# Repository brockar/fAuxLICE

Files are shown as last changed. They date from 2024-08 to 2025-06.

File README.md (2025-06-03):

# fAuxLICE

A 3D printable Alice-like mechanical keyboard.

outside

## Layout

layout

[Keyboard Layout Editor](http://www.keyboard-layout-editor.com/#/gists/7f17a55de07d88c1f975089b07f053b1)

## Components

### Required components

- 1x Arduino Pro Micro
- 64× switches of your choice
- 108-key keycap set
- 64× diodes
- Wires
- 14× M3×16 countersunk screws
- 2× M3×12 countersunk screws

### Optional components

- 4× plate-mounted Costar stabilizers or
- 4x plate-mounted Cherry Mx Spec (Durock Piano)
- 1× M3×8 countersunk screw
- 1× M3×10 countersunk screw
- 1× M3×12 countersunk screw
- 1× M3×16 countersunk screw
- 1× M3×20 countersunk screw

The optional components are for reinforcing the top halves. They're not required.  
A proper glue-up would probably be enough for the two halves.

## Wiring diagram

The keyboard is wired in a 10-row, 7-column configuration.  
We have to solder a cable between the left and right columns as shown in the picture.
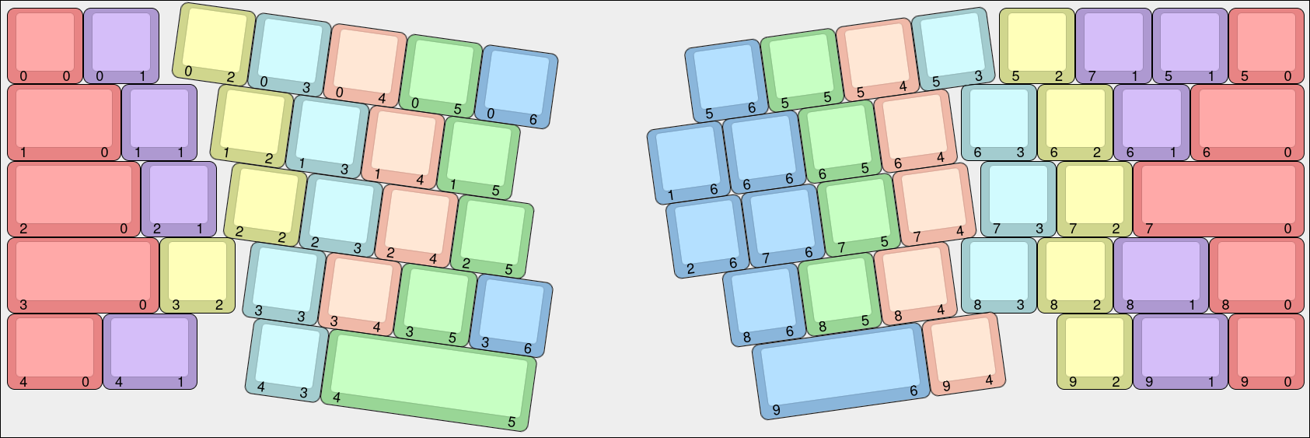
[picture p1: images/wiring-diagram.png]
wiring


The way to connect the rows/columns to the Pro Micro is defined in `keyboard.json`:

```json
"rows": ["B5", "B4", "E6", "D7", "C6", "F4", "D4", "D0", "D1", "D2"],
"cols": ["B6", "B2", "B3", "B1", "F7", "F6", "F5"]
```

## Build notes

The accent pieces have an extra 5mm sticking out. You should be able to cut them to the perfect length, and make the transitions between the two seamless. Glue the accent pieces to the bottom halves.

The halves do not lock into each other. I used a combination of glue and diode trimmings melted into the plastic.

## Firmware

[firmware explain](firmware/readme.md)

The firmware included is for the Arduino Pro Micro board.  
You can just flash `fauxlice_vial.hex` with [QMK-Toolbox](https://qmk.fm/toolbox) or [QMK-CLI](https://docs.qmk.fm/cli).

If you want to change something, download the vial code, create a folder in `vial-qmk/keyboards/` called `fauxlice`, copy what is in `firmware` into that folder, and modify what you need.  
Finally, while in `vial-qmk` run `make fauxlice:vial` and flash the .hex file.

## Build

1. Add mid top screws.
2. Add switches south pole, with the hole to the bottom.
3. Solder the diodes on the left pin (the diagram is top view, but when you're soldering, you're viewing from the bottom).
4. Solder cable as shown on the wiring diagram, and connect the columns to the other side as shown.
5. Now solder the PM as shown in the `keyboard.json`.

Note: If you'll use plate-mounted stabilizers, you should add them before soldering the switches.

## Special thanks to

- [mnt](https://www.instagram.com/mnt.designs/)
- [zykrah](https://zykrah.me/)

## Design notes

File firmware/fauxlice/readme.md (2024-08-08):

# fauxlice

fauxlice

*A short description of the keyboard/project*

* Keyboard Maintainer: [brockar](https://github.com/brockar)
* Hardware Supported: *The PCBs, controllers supported*
* Hardware Availability: *Links to where you can find this hardware*

Make example for this keyboard (after setting up your build environment):

    make fauxlice:default

Flashing example for this keyboard:

    make fauxlice:default:flash

See the [build environment setup](https://docs.qmk.fm/#/getting_started_build_tools) and the [make instructions](https://docs.qmk.fm/#/getting_started_make_guide) for more information. Brand new to QMK? Start with our [Complete Newbs Guide](https://docs.qmk.fm/#/newbs).

## Bootloader

Enter the bootloader in 3 ways:

* **Bootmagic reset**: Hold down the key at (0,0) in the matrix (usually the top left key or Escape) and plug in the keyboard
* **Physical reset button**: Briefly press the button on the back of the PCB - some may have pads you must short instead
* **Keycode in layout**: Press the key mapped to `QK_BOOT` if it is available

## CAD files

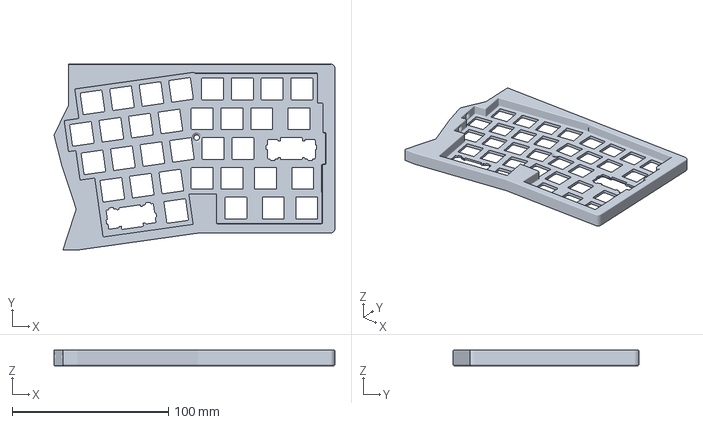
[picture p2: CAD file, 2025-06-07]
STL/fAuxLICE_Top_Right_MxS_Stabs.3mf
179.7 x 119.1 x 10.0 mm

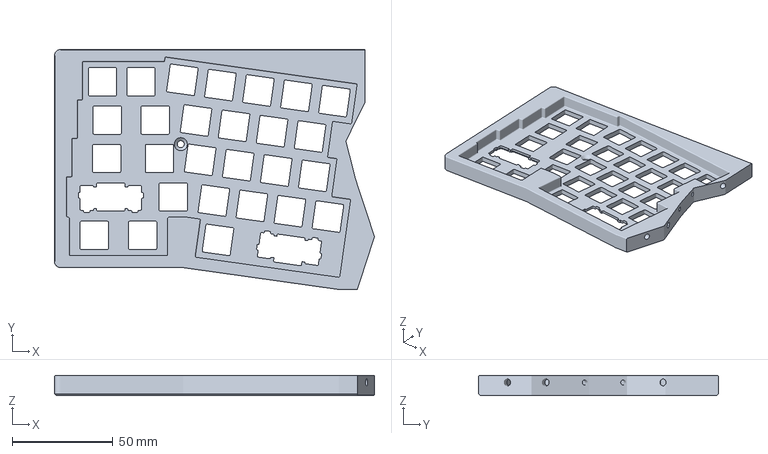
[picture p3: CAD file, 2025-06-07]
STL/fAuxLICE_Top_Left_MxS_Stabs.3mf
158.8 x 119.1 x 10.0 mm

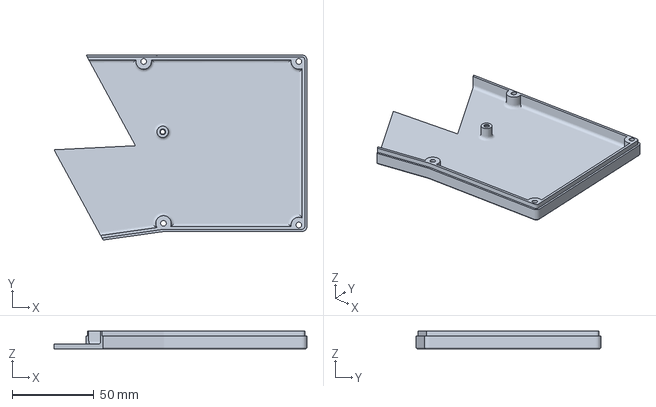
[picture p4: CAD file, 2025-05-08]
STL/fAuxLICE_Bottom_Right.3mf
155.1 x 113.5 x 11.0 mm

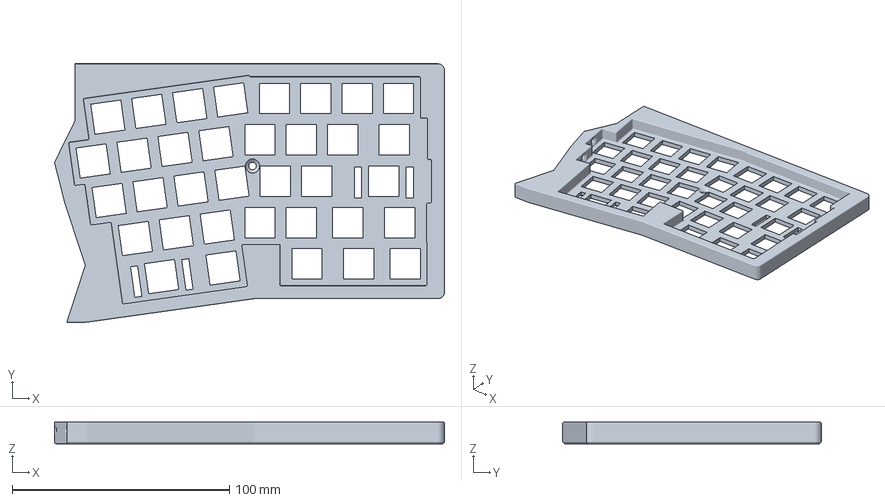
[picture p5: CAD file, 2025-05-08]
STL/fAuxLICE_Top_Right_Costar.3mf
179.7 x 119.1 x 10.0 mm

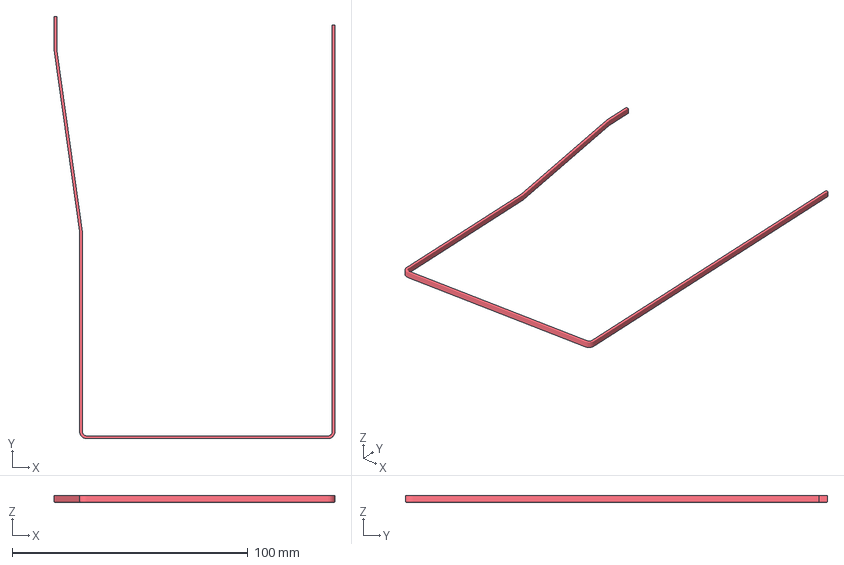
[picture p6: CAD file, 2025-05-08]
STL/fAuxLICE_Accent_Right.3mf
119.1 x 179.0 x 3.00 mm

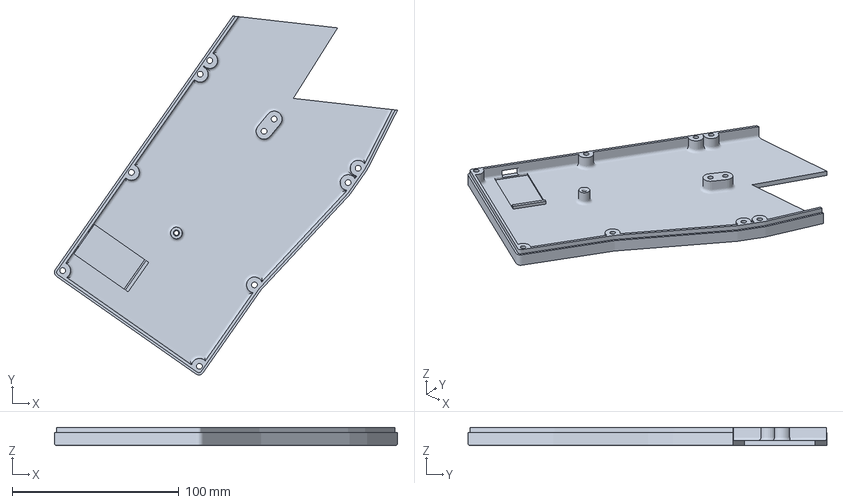
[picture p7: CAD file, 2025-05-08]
STL/fAuxLICE_Bottom_Left.3mf
206.1 x 215.6 x 11.0 mm

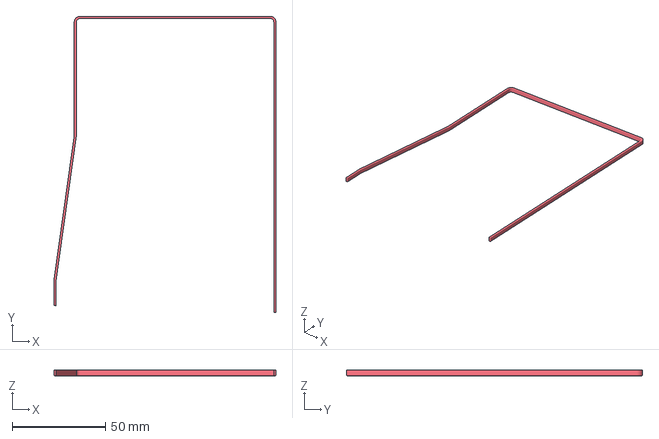
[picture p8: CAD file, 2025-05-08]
STL/fAuxLICE_Accent_Left.3mf
119.1 x 159.0 x 3.00 mm

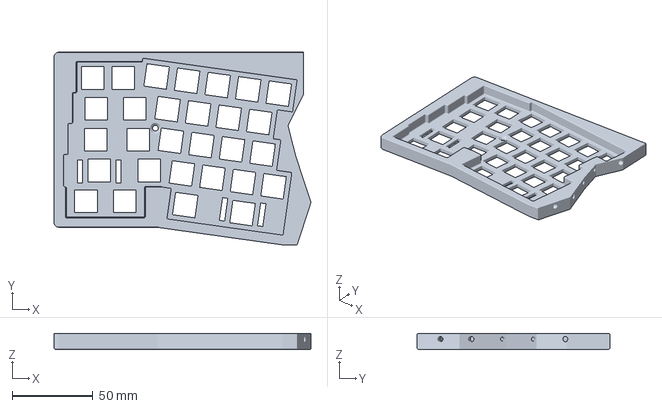
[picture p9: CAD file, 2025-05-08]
STL/fAuxLICE_Top_Left_Costar.3mf
158.8 x 119.1 x 10.0 mm

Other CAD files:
fusion360/fAuxLICE.f3d

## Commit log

2024-10-05 fix case errors
    [fAuxLICE.f3d, fAuxLICE_Accent_Left.3mf, fAuxLICE_Accent_Left.stl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]
2024-10-05 wiring diagram
2025-04-10 STL update (3mf)
    [fAuxLICE_Accent_Left.3mf, fAuxLICE_Accent_Right.3mf, fAuxLICE_Bottom_Left.3mf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]
2025-04-17 oriented 3mf
    [fAuxLICE_Accent_Left.3mf, fAuxLICE_Accent_Right.3mf, fAuxLICE_Bottom_Left.3mf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]
2025-05-05 Add MxS Stabs
    [fAuxLICE_Accent_Left.3mf, fAuxLICE_Accent_Right.3mf, fAuxLICE_Bottom_Left.3mf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]
2025-05-08 fix update
    [fAuxLICE_Accent_Left.3mf, fAuxLICE_Accent_Right.3mf, fAuxLICE_Bottom_Left.3mf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]
2025-06-03 update colors on wiring diagram
2025-06-07 fix mm on left shift
    [fAuxLICE_Top_Left_MxS_Stabs.3mf, fAuxLICE_Top_Right_MxS_Stabs.3mf]
